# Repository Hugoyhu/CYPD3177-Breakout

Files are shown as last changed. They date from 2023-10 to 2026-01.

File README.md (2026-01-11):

# CYPD3177-Breakout
Small 2-layer fixed USB-C PD Power Sink with CYPD3177. Breadboard friendly design, and can easily be assembled on a hot plate if you have a stencil.

The board provides a fixed output of 9V1A using the CYPD3177 chipset. It's highly flexible, allowing USB-C Charging up to 15W and USB-C PD up to 100W. Unlike many other chips available, it does not require any firmware nor flashing, and power settings are configured with pullup and pulldown resistors. This board is set to 9V @ 1A, to ensure maximum compatibility with most PD-capable bricks. It's very compact, measuring less than 22x32mm with breadboard-friendly mounting, an affordable 2-layer design, and single side SMD component placement. 

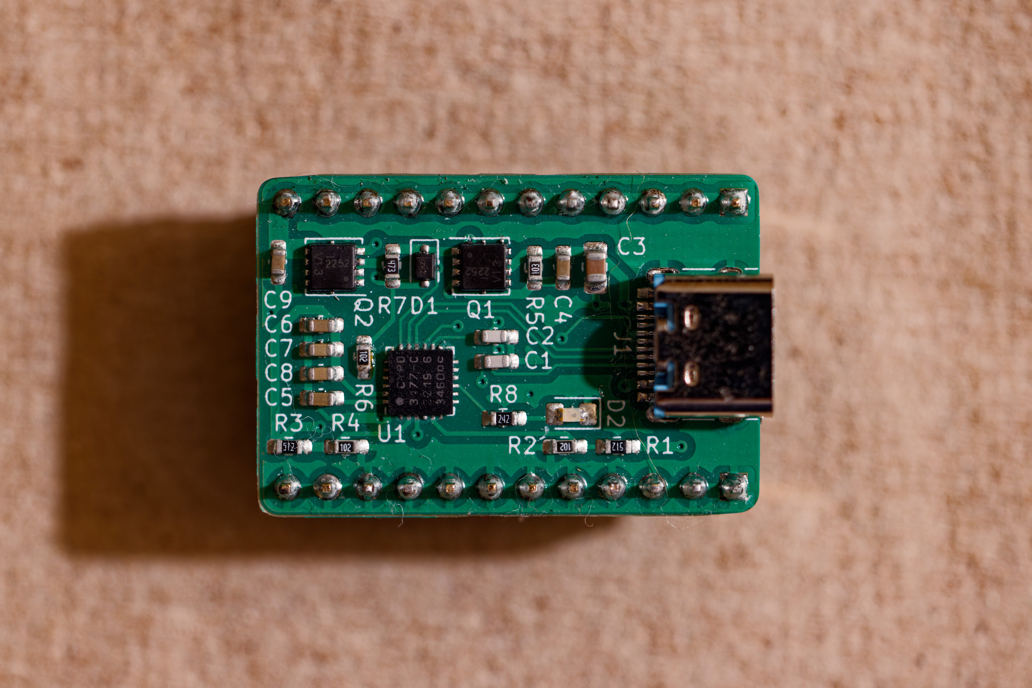
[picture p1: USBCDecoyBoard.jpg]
KiCAD Render of PD Board


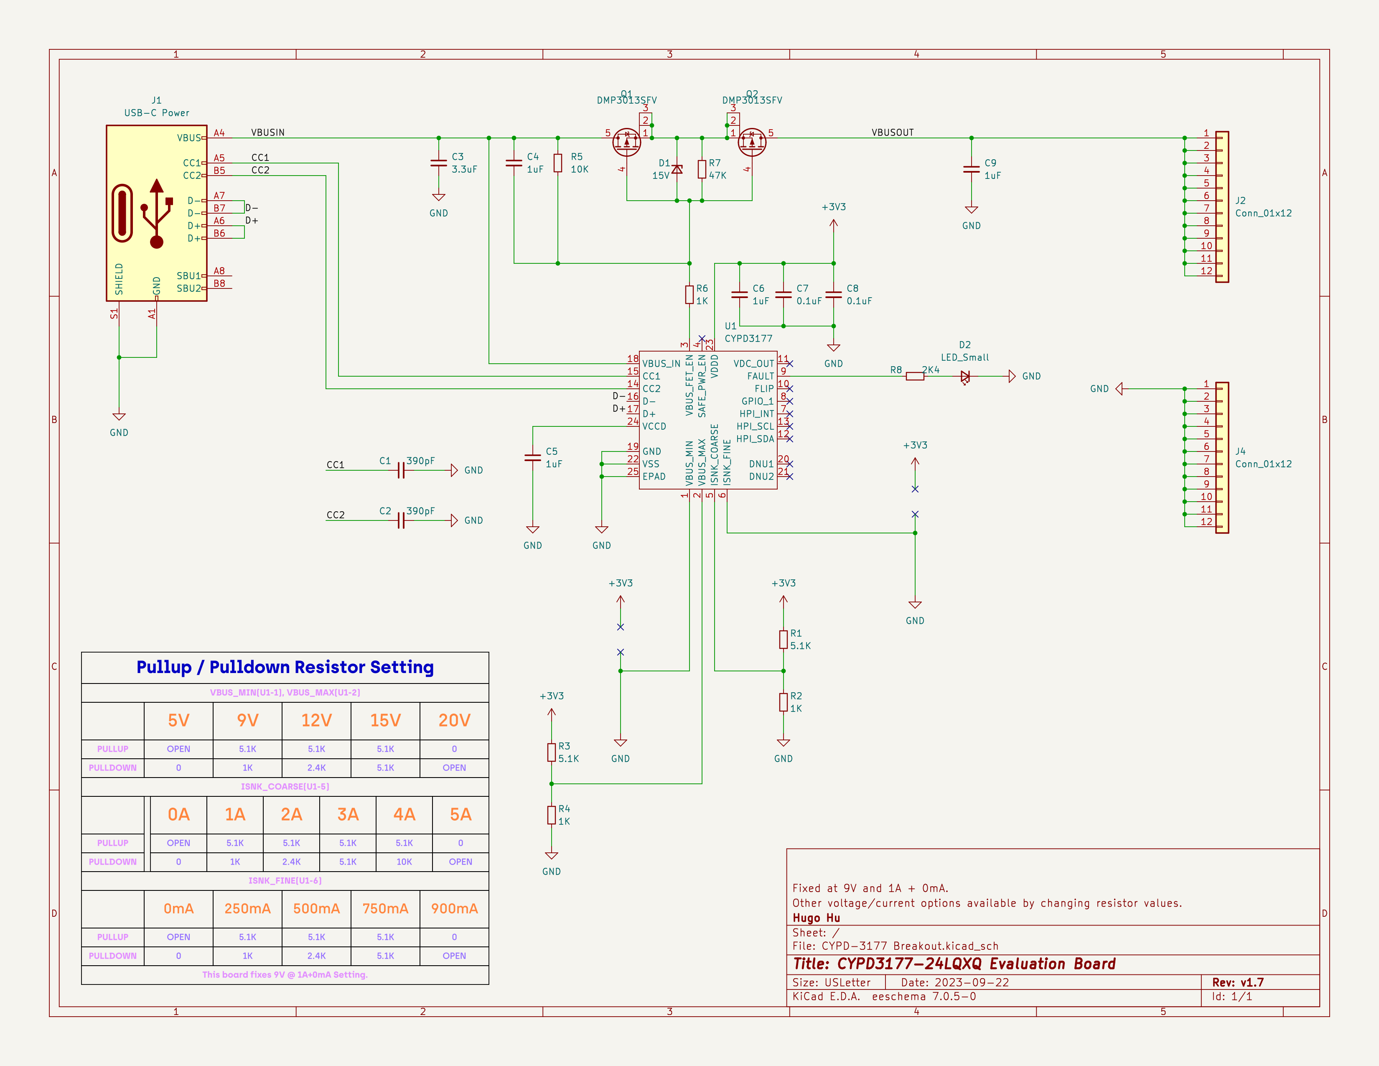
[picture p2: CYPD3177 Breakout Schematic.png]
Schematic


The board is more flexible than off-the-shelf PD boards based on chinese chipsets. They usually only have four pins for mounting, but this board is more mechanically sturdy due to the opposing pins on either side of the board.

You can also modify the design to add switches to configure requested voltage/current during power-on.

*As a precaution: while this board is breadboard friendly, typical solderless breadboards are only rated up to _5V @ 1A_. Do _not_ use this on a solderless breadboard.*
Also, it's important to note the maximum current and voltage that parts on the board can tolerate. For example, if you are looking to adapt the design for a higher current setting, it may be worth considering alternative output connectors: standard 2.54mm headers are only rated for <3A typically. In addition, not all USB-C connectors are rated up to 5A, and not all passives are rated for high voltage tolerance.

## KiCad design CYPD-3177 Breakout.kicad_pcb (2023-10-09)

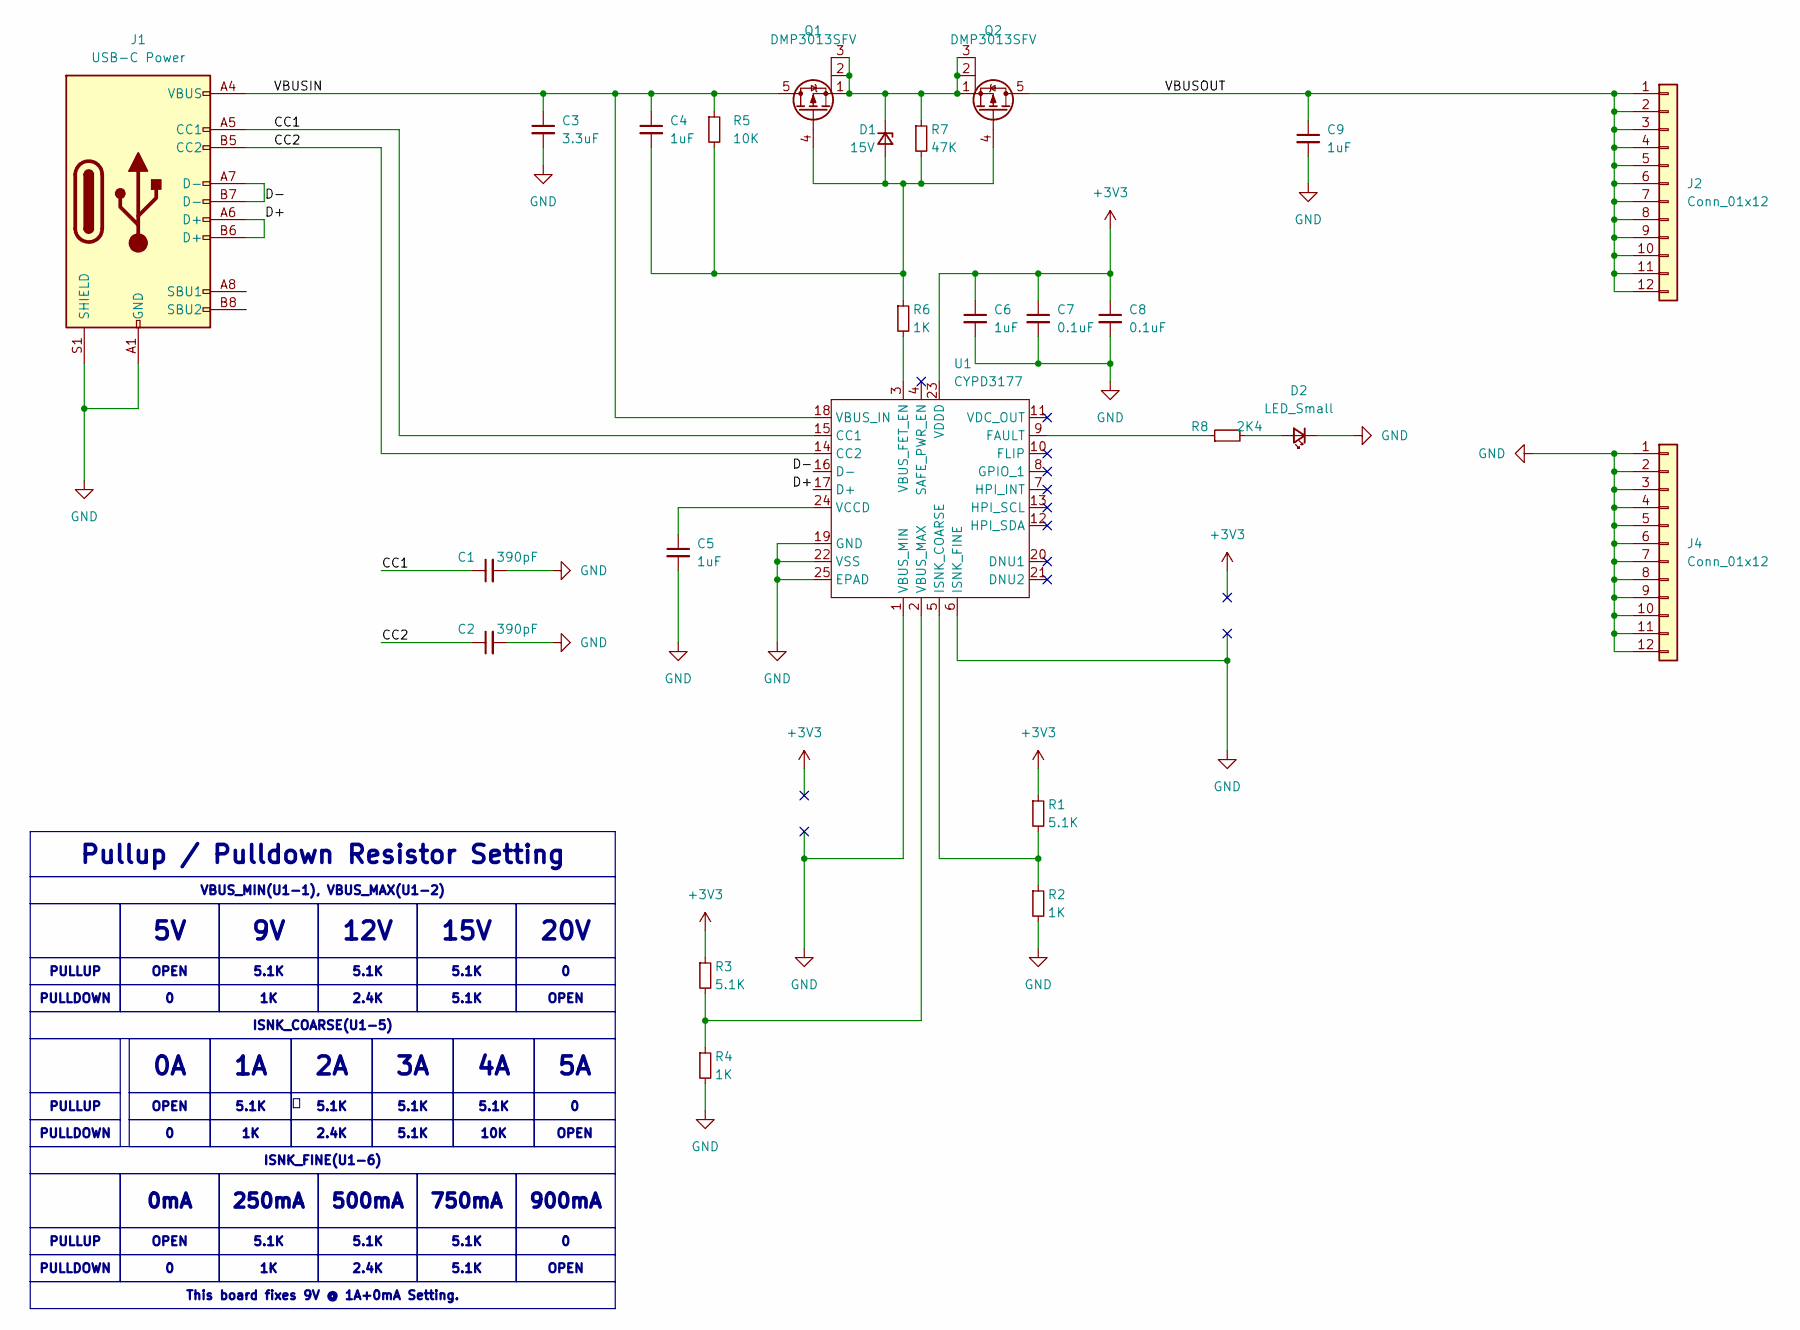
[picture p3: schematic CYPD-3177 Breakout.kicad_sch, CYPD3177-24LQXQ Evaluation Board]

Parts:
C1, C2: 390pF; C_0603_1608Metric_Pad1.08x0.95mm_HandSolder
C3: 3.3uF; C_0805_2012Metric_Pad1.18x1.45mm_HandSolder
C4, C5, C6, C9: 1uF; C_0603_1608Metric_Pad1.08x0.95mm_HandSolder
C7, C8: 0.1uF; C_0603_1608Metric_Pad1.08x0.95mm_HandSolder
D1: 15V; D_SOD-323F
D2: LED_Small; LED_0805_2012Metric_Pad1.15x1.40mm_HandSolder
J1: USB-C Power; USB_C_Receptacle_HRO_TYPE-C-31-M-12
J2, J4: Conn_01x12; PinHeader_1x12_P2.54mm_Vertical
Q1, Q2: DMP3013SFV; Diodes_PowerDI3333-8
R1, R3: 5.1K; R_0603_1608Metric_Pad0.98x0.95mm_HandSolder
R2, R4, R6: 1K; R_0603_1608Metric_Pad0.98x0.95mm_HandSolder
R5: 10K; R_0603_1608Metric_Pad0.98x0.95mm_HandSolder
R7: 47K; R_0603_1608Metric_Pad0.98x0.95mm_HandSolder
R8: 2K4; R_0603_1608Metric_Pad0.98x0.95mm_HandSolder
U1: CYPD3177; QFN-24-1EP_4x4mm_P0.5mm_EP2.7x2.7mm

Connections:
+3V3: C6.1, C7.1, C8.1, R1.1, R3.1, U1.23 (VDDD)
/CC1: C1.1, J1.A5 (CC1), U1.15 (CC1)
/CC2: C2.1, J1.B5 (CC2), U1.14 (CC2)
/D+: J1.A6 (D+), J1.B6 (D+), U1.17 (D+)
/D-: J1.A7 (D-), J1.B7 (D-), U1.16 (D-)
/VBUSIN: C3.1, C4.1, J1.A4 (VBUS), J1.A9 (VBUS), J1.B4 (VBUS), J1.B9 (VBUS), Q1.5 (D), R5.1, U1.18 (VBUS_IN)
/VBUSOUT: C9.1, J2.1, J2.2, J2.3, J2.4, J2.5, J2.6, J2.7, J2.8, J2.9, J2.10, J2.11, J2.12, Q2.5 (D)
GND: C1.2, C2.2, C3.2, C5.2, C6.2, C7.2, C8.2, C9.2, D2.1 (K), J1.A1 (GND), J1.A12 (GND), J1.B1 (GND), J1.B12 (GND), J1.S1 (SHIELD), J4.1, J4.2, J4.3, J4.4, J4.5, J4.6, J4.7, J4.8, J4.9, J4.10, J4.11, J4.12, R2.2, R4.2, U1.1 (VBUS_MIN), U1.6 (ISNK_FINE), U1.19 (GND), U1.22 (VSS), U1.25 (EPAD)
unnamed: C4.2, D1.2 (A), Q1.4 (G), Q2.4 (G), R5.2, R6.1, R7.2
unnamed: D1.1 (K), Q1.1 (S), Q1.2 (S), Q1.3, Q2.1 (S), Q2.2, Q2.3 (S), R7.1
unnamed: D2.2 (A), R8.2
unnamed: R8.1, U1.9 (FAULT)
unnamed: R1.2, R2.1, U1.5 (ISNK_COARSE)
unnamed: R6.2, U1.3 (VBUS_FET_EN)
unnamed: R3.2, R4.1, U1.2 (VBUS_MAX)
unnamed: C5.1, U1.24 (VCCD)

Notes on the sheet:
20V
5.1K
ISNK_COARSE(U1-5)
2.4K
0mA
VBUS_MIN(U1-1), VBUS_MAX(U1-2)
500mA
OPEN
OPEN
10K
15V
This board fixes 9V @ 1A+0mA Setting.
PULLDOWN
12V
250mA
PULLUP
900mA
Pullup / Pulldown Resistor Setting
750mA
ISNK_FINE(U1-6)

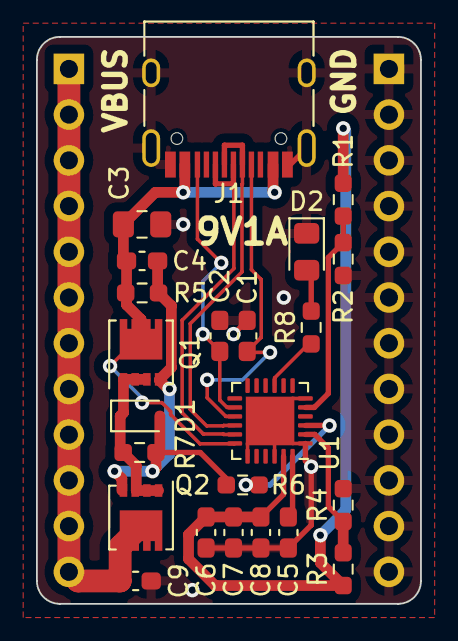
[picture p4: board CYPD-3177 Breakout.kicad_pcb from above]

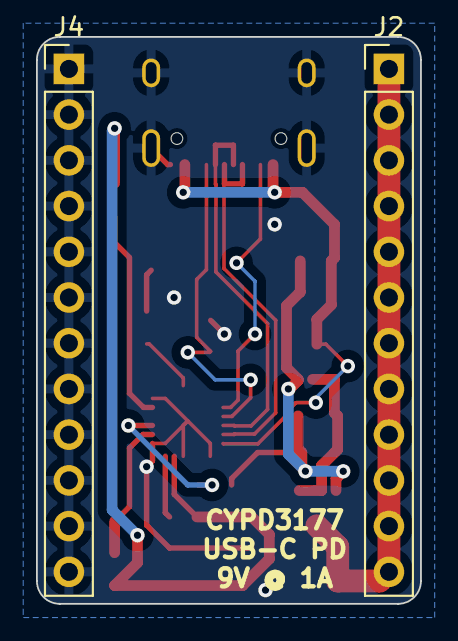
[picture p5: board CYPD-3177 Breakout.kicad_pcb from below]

Board: 2 copper layers, 21.3 x 31.5 mm, 25 parts (2 on the bottom side), 16 nets.

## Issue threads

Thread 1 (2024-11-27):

VDC_OUT not connected

piecol, 2024-11-27:
Hi,

why is this pin not connected in your schematics? the datasheet states this:

> Connect this pin to the output of the PFETs controlled by the VBUS_FET_EN. This is used for
> monitoring the VBUS output. This is the power output of the system.

Hugoyhu, 2024-12-02:
Good question. I honestly don't remember the thought process I had while designing this. But it does seem to work at least at 9V@1A - sorry I don't have a better answer for you

Closed 2024-12-02.
